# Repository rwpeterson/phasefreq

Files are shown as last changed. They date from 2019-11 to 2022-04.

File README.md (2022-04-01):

# phasefreq
 Phase-frequency detector PCB built around the AD9901

## Design goals

* Simple, connectorized element to replace an analog mixer in rf test setups
* Requires only dc power to operate (no programming)
* 10 MHz, ideally 100 MHz bandwidth (10 MHz is reasonable without impedance control in fabrication)
* Accommodate analog input (Analog ADCMP564 comparator, with settable threshold and hysteresis)
* Perform PFD calculation (Analog AD9901 phase-frequency discriminator, ECL logic family)
* Low-pass filter to convert PFD output's pulse train duty cycle to a dc voltage
* Tunable output offset, jumper-switchable sign of gain
* This is basically a subset of the reference design in Fig. 12 of the [AD9901 datasheet](https://www.analog.com/media/en/technical-documentation/data-sheets/AD9901.pdf), which describes a complete PLL circuit with discrete comparator, PFD, VCO, divider, etc. Here we wish to implement only the comparator, phase-frequency detector, and loop filter

## What is a PFD?

A phase-frequency detector (or phase-frequency discriminator) is similar to an analog mixer, in that if the LO and RF frequencies are the same, its output is proportional to the relative phase between them. However, if the LO and RF frequencies differ, a PFD will output a constant voltage whose sign indicates which of the two frequencies is larger. In this case, an analog mixer would produce IF beatnotes at the sum and difference frequencies. This second characteristic of a PFD is useful to more quickly bring a feedback system such as a PLL into lock.

## Other options?

Of course, an analog mixer may be perfectly suitable for your application. More sophisticated PLL ICs contain builtin PFDs as part of the feedback loop. Some evaluation boards expose enough functionality to use them solely as a PFD, but they are prohibitively expensive for many applications where a simple PFD would be beneficial, and often need to be programmed or initialized at the point of use.

## Characterization

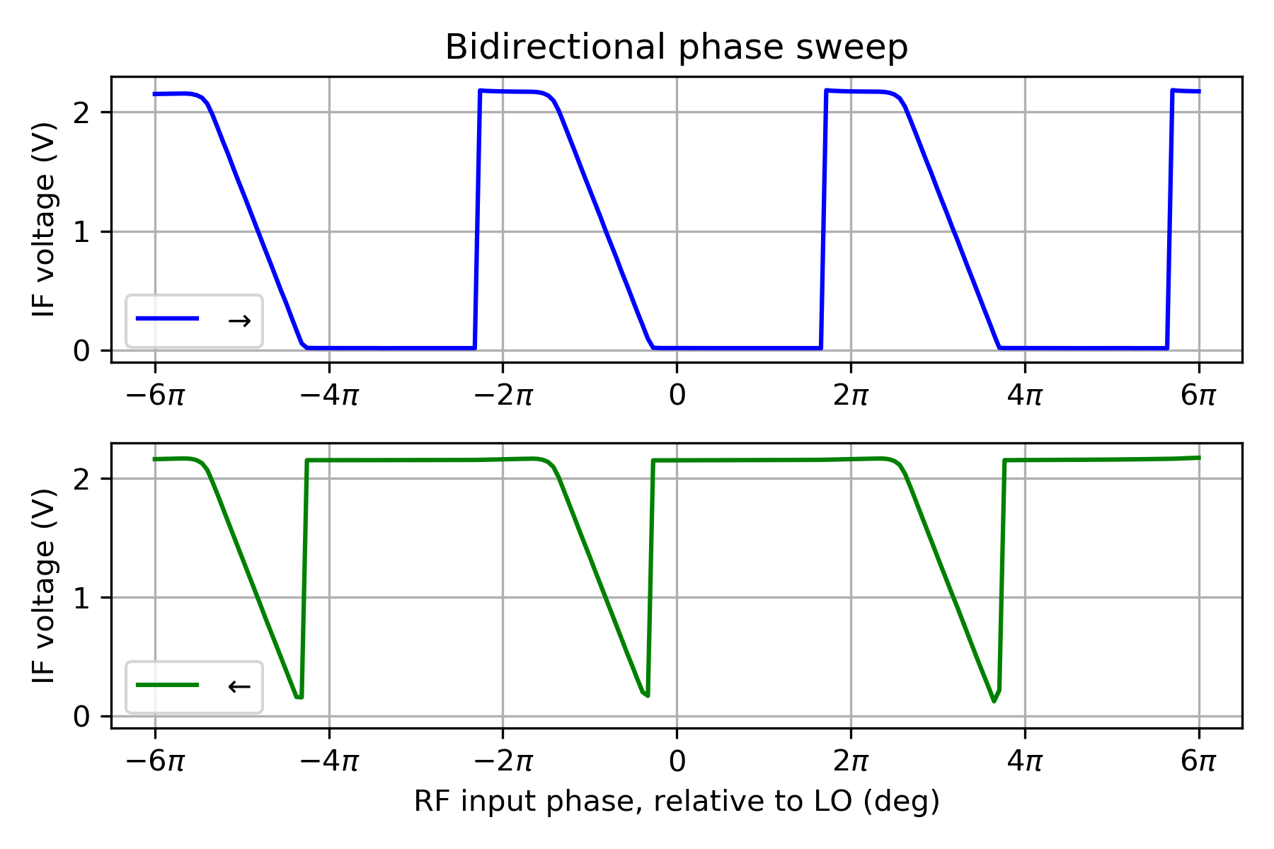
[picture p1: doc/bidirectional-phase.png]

### Figure 1: Bidirectional phase sweep (RF and LO at 10 MHz)
Scanning the relative phase of the inputs demonstrates the linear phase detection and capture range. The location of the linear phase detection is modulo 2 pi as expected. However, when the phase is scanned away from a given phase detection range, the IF output will rail for one additional phase cycle before phase-slipping to the *second* capture range 4 pi away (as shown). For frequencies > 50 MHz, the ends of the phase detection range will be distorted (see AD9901 datasheet, Fig. 7).

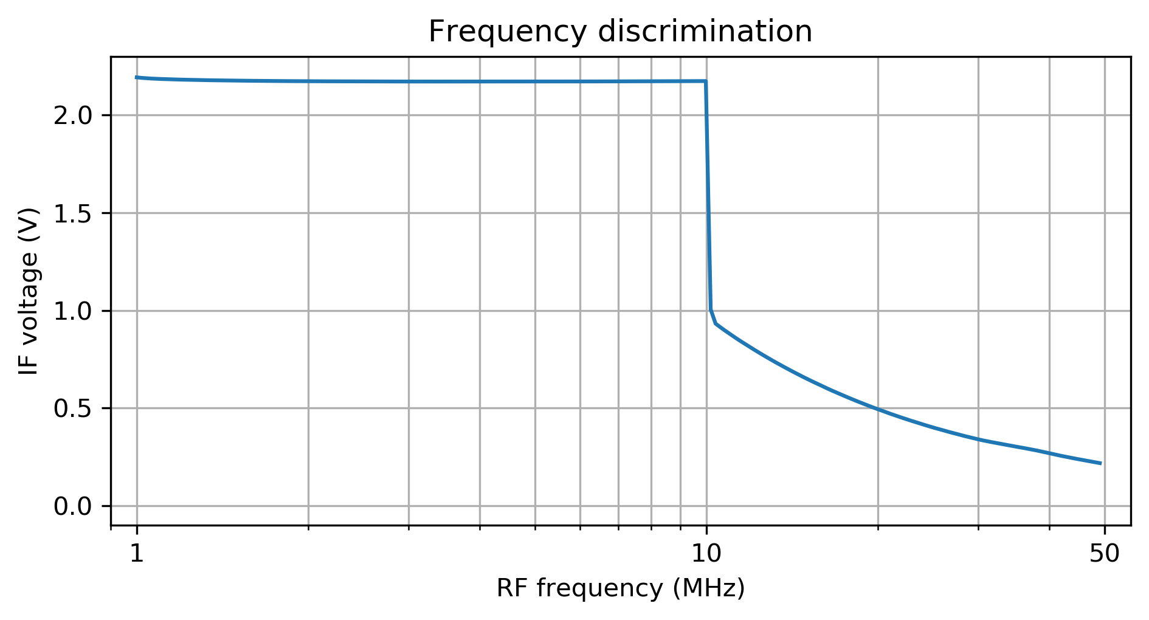
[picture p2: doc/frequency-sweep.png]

### Figure 2: Frequency discrimination characteristic, LO = 10 MHz
When the RF and LO frequencies differ substantially, the PFD outputs a constant voltage indicating which is higher.

## Prototype

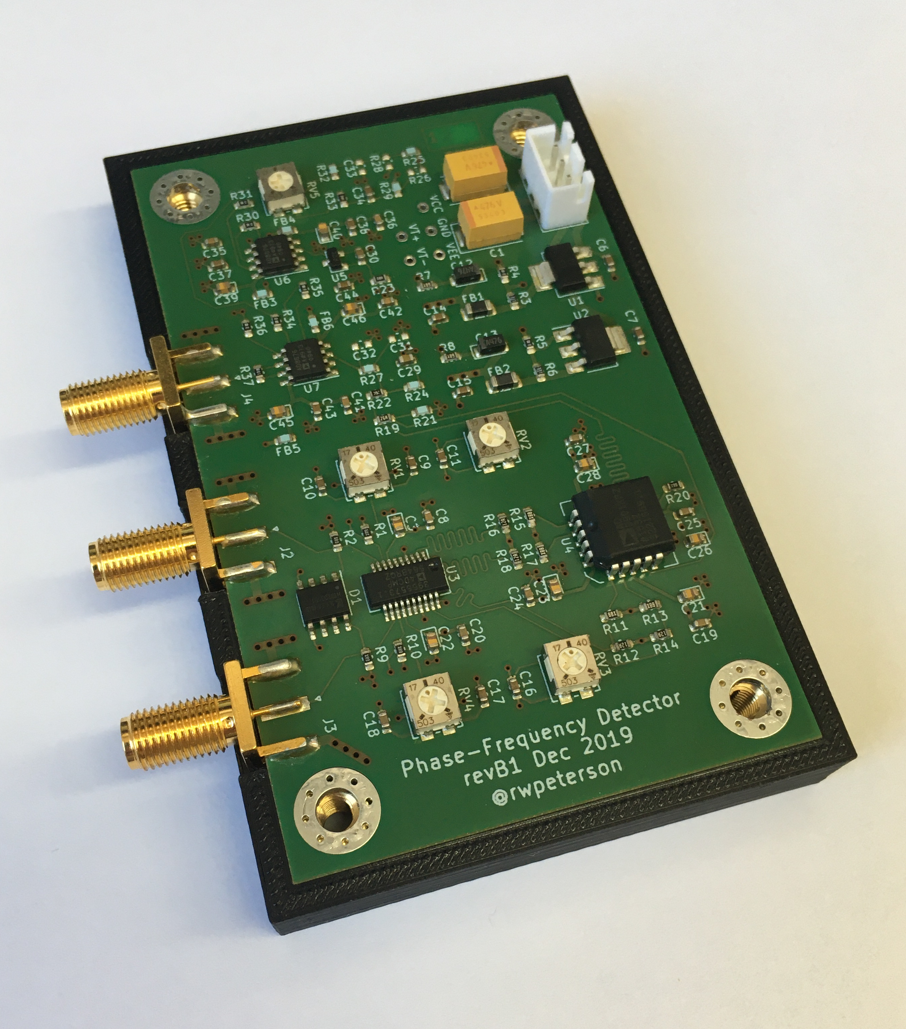
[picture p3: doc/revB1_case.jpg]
Prototype

### Figure 3: revB1 prototype in 3D-printed case (lid removed)
This is the device used for the above characterization plots.

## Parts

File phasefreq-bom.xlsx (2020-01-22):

Source: | phasefreq.sch
Date: | 2019-11-12 11:08
Tool: | Eeschema (5.1.2)-1
Generator: | C:\Program Files\KiCad\bin\scripting\plugins/bom_csv_grouped_by_value_with_fp.py
Component Count: | 100
Ref | Qnty | Value | Cmp name | Footprint | Description | Vendor | Link
C1, C4, | 2 | 47u | CP_Small | Capacitor_Tantalum_SMD:CP_EIA-7343-43_Kemet-X | Polarized capacitor, small symbol |  | https://www.digikey.at/product-detail/en/avx-corporation/TAJE476K035RNJ/478-3074-1-ND/809587
C8, C20, C27, C25, C19, C24, | 6 | 10n | C_Small | Capacitor_SMD:C_0603_1608Metric | Unpolarized capacitor, small symbol |  | https://www.digikey.at/product-detail/en/murata-electronics/GCJ188R71H103KA01D/490-5762-1-ND/2782239
C13, C12, | 2 | 47u | CP_Small | Capacitor_Tantalum_SMD:CP_EIA-3216-18_Kemet-A | Polarized capacitor, small symbol |  | https://www.digikey.at/product-detail/en/avx-corporation/F931A476KAA/478-8223-1-ND/4005652
C17, C18, C43, C44, C14, C15, C7, C11, C16, C6, C37, C38, C30, C10, C9, C34, | 16 | 100n | C_Small | Capacitor_SMD:C_0603_1608Metric | Unpolarized capacitor, small symbol |  | https://www.digikey.at/product-detail/en/murata-electronics/GCJ188R71H104KA12D/490-5798-1-ND/2783823
C22, C26, C21, C23, C3, C28, | 6 | 1u | CP_Small | Capacitor_Tantalum_SMD:CP_EIA-1608-10_AVX-L | Polarized capacitor, small symbol |  | https://www.digikey.at/product-detail/en/avx-corporation/TACL105K010RTA/478-7521-1-ND/3660394
C29, | 1 | 1u | C_Small | Capacitor_SMD:C_0603_1608Metric | Unpolarized capacitor, small symbol |  | https://www.digikey.at/product-detail/en/taiyo-yuden/UMK107AB7105KA-T/587-3247-1-ND/3660107
C32, C31, C33, | 3 | DNP | C_Small | Capacitor_SMD:C_0603_1608Metric | Unpolarized capacitor, small symbol |  | -
C41, C42, C35, C36, | 4 | 1n | C_Small | Capacitor_SMD:C_0603_1608Metric | Unpolarized capacitor, small symbol |  | https://www.digikey.at/product-detail/en/murata-electronics/GCJ188R71H102KA01D/490-5768-1-ND/2782248
C45, C46, C39, C40, | 4 | 4u7 | CP_Small | Capacitor_Tantalum_SMD:CP_EIA-1608-10_AVX-L | Polarized capacitor, small symbol |  | https://www.digikey.at/product-detail/en/avx-corporation/TPCL475K010R5000/478-4961-1-ND/1879558
D1, | 1 | SLVU2.8-8 | SLVU2.8-8 | Package_SO:SOIC-8_3.9x4.9mm_P1.27mm | SLVU2.8-8 Series 2.8V 30A TVS Array |  | https://www.digikey.at/product-detail/en/littelfuse-inc/SLVU2.8-8BTG/F6745CT-ND/5428749
FB2, FB1, | 2 | BLM31PG601SN1L | Ferrite_Bead_Small | Inductor_SMD:L_1206_3216Metric | Ferrite bead, small symbol |  | https://www.digikey.at/product-detail/en/murata-electronics/BLM31PG601SN1L/490-1057-1-ND/584503
J1, | 1 | Power Input | Conn_01x03_Female | Connector_JST:JST_XH_B3B-XH-A_1x03_P2.50mm_Vertical | Generic connector, single row, 01x03, script generated (kicad-library-utils/schlib/autogen/connector/) |  | -
J2, | 1 | RF Input | Conn_Coaxial | Connector_Coaxial:SMA_Amphenol_132289_EdgeMount | coaxial connector (BNC, SMA, SMB, SMC, Cinch/RCA, ...) |  | https://www.digikey.at/product-detail/en/amphenol-rf/132289/ACX1426-ND/1989875
J3, | 1 | LO Input | Conn_Coaxial | Connector_Coaxial:SMA_Amphenol_132289_EdgeMount | coaxial connector (BNC, SMA, SMB, SMC, Cinch/RCA, ...) |  | ^
J4, | 1 | VCO Tune | Conn_Coaxial | Connector_Coaxial:SMA_Amphenol_132289_EdgeMount | coaxial connector (BNC, SMA, SMB, SMC, Cinch/RCA, ...) |  | ^
R2, R10, R9, R1, | 4 | 49R9 | R_Small | Resistor_SMD:R_0603_1608Metric | Resistor, small symbol |  | https://www.digikey.at/product-detail/en/stackpole-electronics-inc/RNCP0603FTD49R9/RNCP0603FTD49R9CT-ND/2240419
R6, R3, | 2 | 330 | R_Small | Resistor_SMD:R_0603_1608Metric | Resistor, small symbol |  | https://www.digikey.at/product-detail/en/yageo/RT0603FRE07330RL/YAG5957CT-ND/9370987
R8, R7, | 2 | 5R0 | R_Small | Resistor_SMD:R_0603_1608Metric | Resistor, small symbol |  | https://www.digikey.at/product-detail/en/te-connectivity-passive-product/CPF0603F4R99C1/A102290CT-ND/2728264
R11, R13, R15, R17, | 4 | 80R6 | R_Small | Resistor_SMD:R_0603_1608Metric | Resistor, small symbol |  | https://www.digikey.at/product-detail/en/te-connectivity-passive-product/RP73PF1J80R6BTDF/A110003CT-ND/4034358
R12, R14, R16, R18, | 4 | 130 | R_Small | Resistor_SMD:R_0603_1608Metric | Resistor, small symbol |  | https://www.digikey.at/product-detail/en/te-connectivity-passive-product/RP73PF1J130RBTDF/A110023CT-ND/4034378
R19, | 1 | 182 | R_Small | Resistor_SMD:R_0603_1608Metric | Resistor, small symbol |  | https://www.digikey.at/product-detail/en/te-connectivity-passive-product/RP73PF1J182RBTDF/A110037CT-ND/4034392
R20, | 1 | 47R5 | R_Small | Resistor_SMD:R_0603_1608Metric | Resistor, small symbol |  | https://www.digikey.at/product-detail/en/stackpole-electronics-inc/RNCP0603FTD47R5/RNCP0603FTD47R5CT-ND/2240418
R22, | 1 | 18K2 | R_Small | Resistor_SMD:R_0603_1608Metric | Resistor, small symbol |  | https://www.digikey.at/product-detail/en/stackpole-electronics-inc/RNCP0603FTD18K2/RNCP0603FTD18K2CT-ND/2240486
R23, | 1 | 499R | R_Small | Resistor_SMD:R_0603_1608Metric | Resistor, small symbol |  | https://www.digikey.at/product-detail/en/stackpole-electronics-inc/RNCP0603FTD499R/RNCP0603FTD499RCT-ND/2240437
R24, | 1 | 110 | R_Small | Resistor_SMD:R_0603_1608Metric | Resistor, small symbol |  | https://www.digikey.at/product-detail/en/vishay-beyschlag/MCT06030C1100FP500/749-MCT06030C1100FP500CT-ND/10453856
R27, R21, R32, R29, R25, | 5 | 0R0 | R_Small | Resistor_SMD:R_0603_1608Metric | Resistor, small symbol |  | https://www.digikey.at/product-detail/en/vishay-beyschlag/MCT06030Z0000ZP500/MCT0603-0.0-ZZCT-ND/2607921
R28, R26, | 2 | DNP | R_Small | Resistor_SMD:R_0603_1608Metric | Resistor, small symbol |  | -
R33, | 1 | 28K | R_Small | Resistor_SMD:R_0603_1608Metric | Resistor, small symbol |  | https://www.digikey.at/product-detail/en/stackpole-electronics-inc/RNCP0603FTD28K0/RNCP0603FTD28K0CT-ND/2240493
R35, R34, R5, R4, R30, R31, R36, | 7 | 1K | R_Small | Resistor_SMD:R_0603_1608Metric | Resistor, small symbol |  | https://www.digikey.at/product-detail/en/stackpole-electronics-inc/RNCP0603FTD1K00/RNCP0603FTD1K00CT-ND/2240445
R37, | 1 | 1K50 | R_Small | Resistor_SMD:R_0603_1608Metric | Resistor, small symbol |  | https://www.digikey.at/product-detail/en/stackpole-electronics-inc/RNCP0603FTD1K50/RNCP0603FTD1K50CT-ND/2240449
RV2, RV3, RV1, RV4, RV5, | 5 | 50K | R_POT | Potentiometer_SMD:Potentiometer_Vishay_TS53YJ_Vertical | Potentiometer |  | https://www.digikey.at/product-detail/en/vishay-sfernice/TS53YJ503MR10/TS53YJ-50KCT-ND/1587989
U1, | 1 | LM317_3PinPackage | LM317_3PinPackage | Package_TO_SOT_SMD:SOT-223-3_TabPin2 | 1A 35V Adjustable Linear Regulator, SOT-89/SOT-223/TO-220/TO-252/TO-263 |  | https://www.digikey.at/product-detail/en/texas-instruments/LM317DCY/296-23224-5-ND/1510131
U2, | 1 | LM337_SOT223 | LM337_SOT223 | Package_TO_SOT_SMD:SOT-223-3_TabPin2 | Negative 1A 35V Adjustable Linear Regulator, SOT-223 |  | https://www.digikey.at/product-detail/en/texas-instruments/LM337IMP-NOPB/LM337IMP-NOPBCT-ND/270746
U3, | 1 | ADCMP564 | ADCMP564 | Package_SO:QSOP-20_3.9x8.7mm_P0.635mm |  |  | https://www.digikey.at/product-detail/en/analog-devices-inc/ADCMP564BRQZ/ADCMP564BRQZ-ND/997466
U4, | 1 | AD9901 | AD9901 | Package_LCC:PLCC-20 |  |  | https://www.digikey.at/product-detail/en/analog-devices-inc/AD9901KPZ/AD9901KPZ-ND/820034
U5, | 1 | LM4040DIZ-2.5 | LM4040DBZ-3 | Package_TO_SOT_SMD:SOT-23 | 3.000V Precision Micropower Shunt Voltage Reference, SOT-23 |  | https://www.digikey.at/product-detail/en/diodes-incorporated/LM4040C25FTA/LM4040C25FCT-ND/1557754
U6, U7, | 2 | AD8676 | AD8676 | Package_SO:SOIC-8_3.9x4.9mm_P1.27mm |  |  | https://www.digikey.at/product-detail/en/analog-devices-inc/AD8676ARZ-REEL7/AD8676ARZ-REEL7CT-ND/3828889

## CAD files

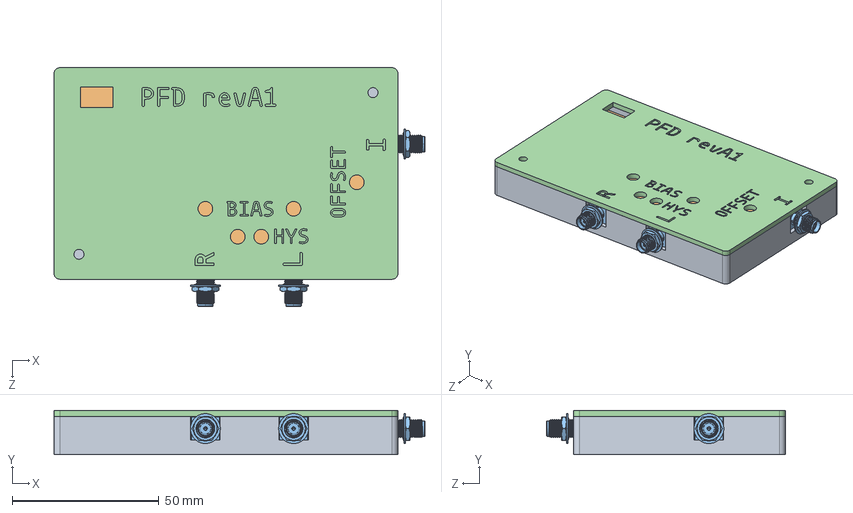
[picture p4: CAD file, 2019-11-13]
Enclosure/PFD Enclosure.SLDASM
126.2 x 15.0 x 81.2 mm
PFD Enclosure Base
PFD Board Primitive
PFD Enclosure Lid

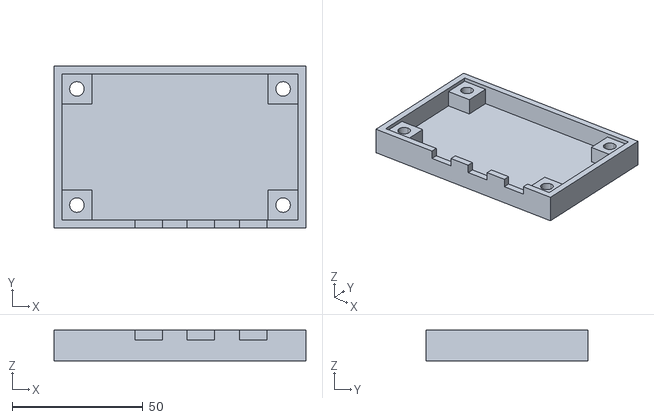
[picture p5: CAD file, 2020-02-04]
enclosure-base.stl
96.5 x 62.0 x 11.8

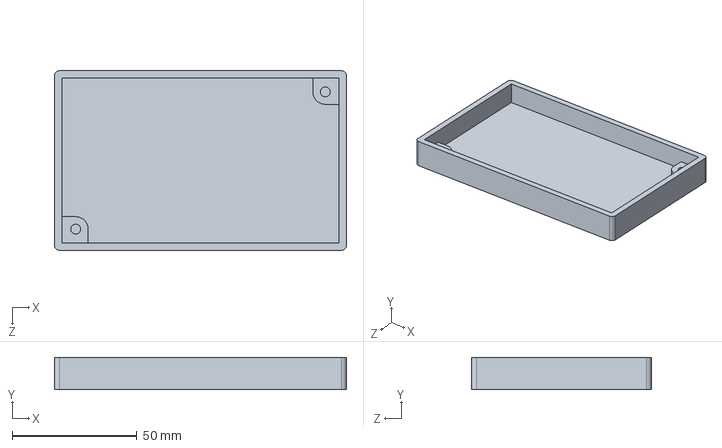
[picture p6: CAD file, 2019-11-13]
Enclosure/PFD Enclosure Base.SLDPRT
117.0 x 13.0 x 72.0 mm

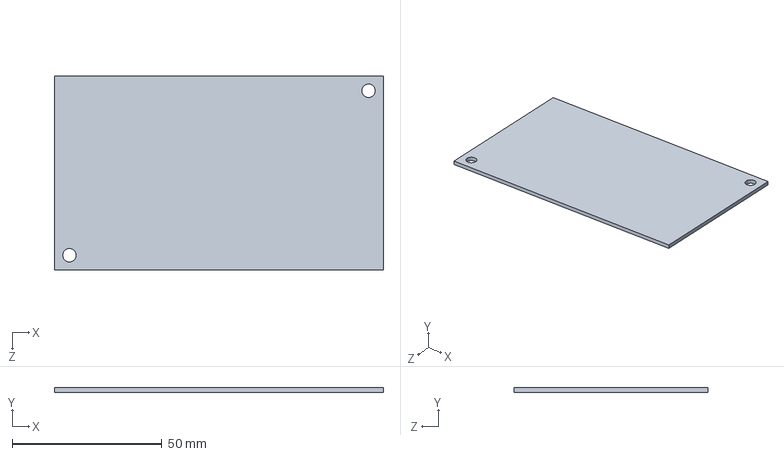
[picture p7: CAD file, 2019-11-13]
Enclosure/PFD Board Primitive.SLDPRT
110.0 x 1.60 x 65.0 mm

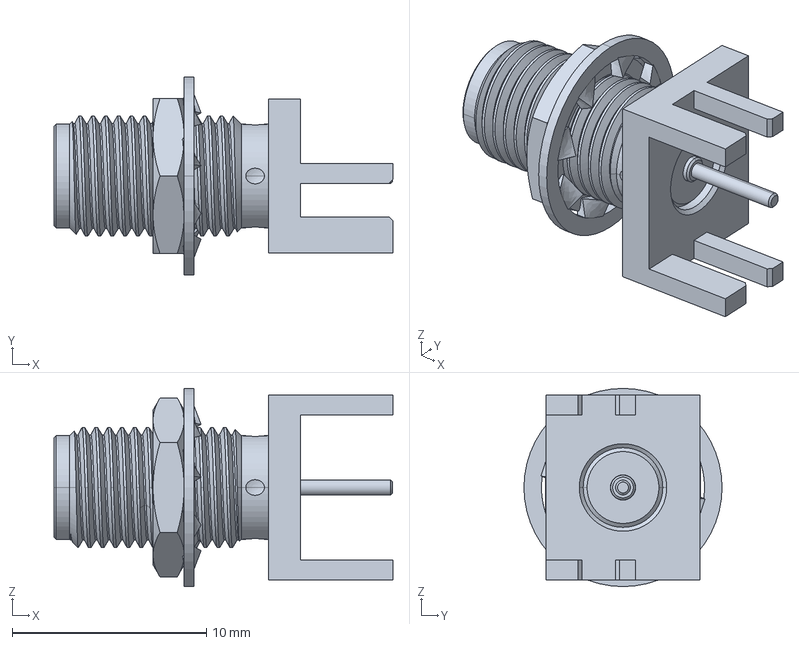
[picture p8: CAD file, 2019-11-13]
Enclosure/132289.stp
17.5 x 10.2 x 10.2 mm

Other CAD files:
Enclosure/PFD Enclosure Lid.sldprt
phasefreq.wrl_0.sldprt
Enclosure/PFD Board.sldprt
Enclosure/132289.SLDPRT
Enclosure/PFD Enclosure Base.STL
Enclosure/PFD Enclosure Lid.STL

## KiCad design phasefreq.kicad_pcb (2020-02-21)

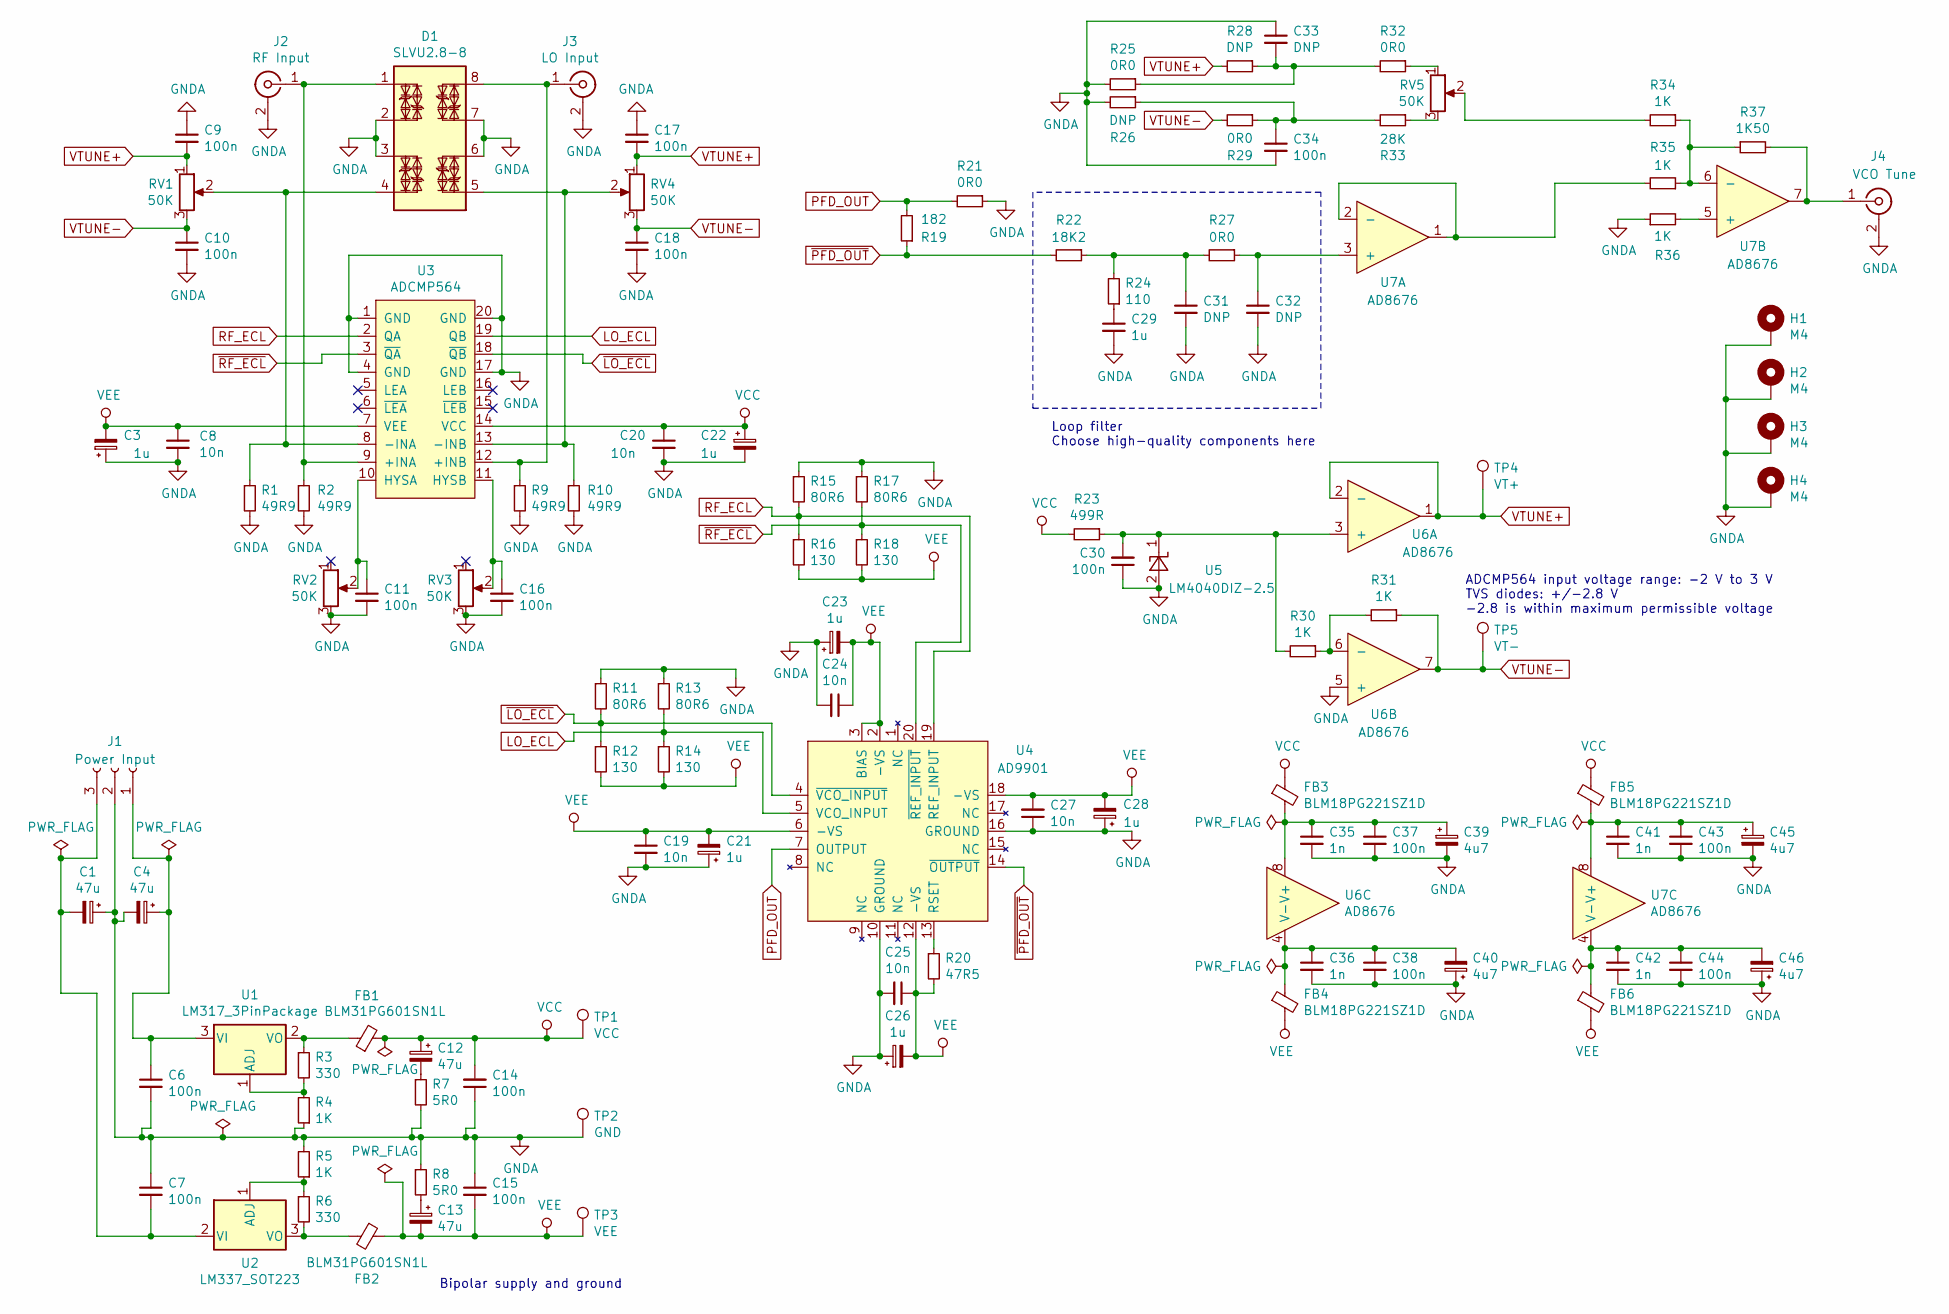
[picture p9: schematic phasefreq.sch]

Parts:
C1, C4: 47u; CP_EIA-7343-43_Kemet-X
C3, C21, C22, C23, C26, C28: 1u; CP_EIA-1608-10_AVX-L
C6, C7, C9, C10, C11, C14, C15, C16, C17, C18, C30, C34, C37, C38, C43, C44: 100n; C_0603_1608Metric
C8, C19, C20, C24, C25, C27: 10n; C_0603_1608Metric
C12, C13: 47u; CP_EIA-3216-18_Kemet-A
C29: 1u; C_0603_1608Metric
C31, C32, C33: DNP; C_0603_1608Metric
C35, C36, C41, C42: 1n; C_0603_1608Metric
C39, C40, C45, C46: 4u7; CP_EIA-1608-10_AVX-L
D1: SLVU2.8-8; SOIC-8_3.9x4.9mm_P1.27mm
FB1, FB2: BLM31PG601SN1L; L_1206_3216Metric
FB3, FB4, FB5, FB6: BLM18PG221SZ1D; L_0603_1608Metric
H1, H2, H3, H4: M4; MountingHole_4.3mm_M4_Pad_Via
J1: Power Input; JST_XH_B3B-XH-A_1x03_P2.50mm_Vertical
J2: RF Input; SMA_Amphenol_132289_EdgeMount
J3: LO Input; SMA_Amphenol_132289_EdgeMount
J4: VCO Tune; SMA_Amphenol_132289_EdgeMount
R1, R2, R9, R10: 49R9; R_0603_1608Metric
R3, R6: 330; R_0603_1608Metric
R4, R5, R30, R31, R34, R35, R36: 1K; R_0603_1608Metric
R7, R8: 5R0; R_0603_1608Metric
R11, R13, R15, R17: 80R6; R_0603_1608Metric
R12, R14, R16, R18: 130; R_0603_1608Metric
R19: 182; R_0603_1608Metric
R20: 47R5; R_0603_1608Metric
R21, R25, R27, R29, R32: 0R0; R_0603_1608Metric
R22: 18K2; R_0603_1608Metric
R23: 499R; R_0603_1608Metric
R24: 110; R_0603_1608Metric
R26, R28: DNP; R_0603_1608Metric
R33: 28K; R_0603_1608Metric
R37: 1K50; R_0603_1608Metric
RV1, RV2, RV3, RV4, RV5: 50K; Potentiometer_Vishay_TS53YJ_Vertical
TP1: VCC; TestPoint_THTPad_D1.5mm_Drill0.7mm
TP2: GND; TestPoint_THTPad_D1.5mm_Drill0.7mm
TP3: VEE; TestPoint_THTPad_D1.5mm_Drill0.7mm
TP4: VT+; TestPoint_THTPad_D1.5mm_Drill0.7mm
TP5: VT-; TestPoint_THTPad_D1.5mm_Drill0.7mm
U1: LM317_3PinPackage; SOT-223-3_TabPin2
U2: LM337_SOT223; SOT-223-3_TabPin2
U3: ADCMP564; QSOP-20_3.9x8.7mm_P0.635mm
U4: AD9901; PLCC-20
U5: LM4040DIZ-2.5; SOT-23
U6, U7: AD8676; SOIC-8_3.9x4.9mm_P1.27mm

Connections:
GNDA: C1.1, C3.1, C4.2, C6.2, C7.1, C8.2, C9.1, C10.2, C11.2, C14.1, C15.1, C16.2, C17.1, C18.2, C19.2, C20.2, C21.1, C22.2, C23.1, C24.2, C25.2, C26.1, C27.1, C28.1, C29.2, C30.1, C31.2, C32.2, C33.1, C34.2, C35.2, C36.2, C37.2, C38.2, C39.2, C40.1, C41.2, C42.2, C43.2, C44.2, C45.2, C46.1, D1.2 (TVS2), D1.3 (TVS1), D1.6 (TVS2), D1.7 (TVS1), H1.1, H2.1, H3.1, H4.1, J1.2, J2.2 (Ext), J3.2 (Ext), J4.2 (Ext), R1.2, R2.2, R4.1, R5.2, R7.2, R8.1, R9.2, R10.2, R11.1, R13.1, R15.1, R17.1, R21.1, R25.2, R26.2, R36.1, RV2.3, RV3.3, TP2.1, U3.1 (GND), U3.4 (GND), U3.17 (GND), U3.20 (GND), U4.10 (GROUND), U4.16 (GROUND), U5.2 (A), U6.5 (+); also elsewhere on the board
LO_ECL: R13.2, R14.1, U3.19 (QB), U4.5 (VCO_INPUT)
unnamed: C1.2, C7.2, J1.3, U2.2 (VI)
unnamed: C4.1, C6.1, J1.1, U1.3 (VI)
unnamed: C11.1, RV2.2, U3.10 (HYSA)
unnamed: C12.2, R7.1
unnamed: C13.1, R8.2
unnamed: C16.1, RV3.2, U3.11 (HYSB)
unnamed: C29.1, R24.1
unnamed: C30.2, R23.1, R30.2, U5.1 (K), U6.3 (+)
unnamed: C31.1, R22.1, R24.2, R27.2
unnamed: C32.1, R27.1, U7.3 (+)
unnamed: C33.2, R25.1, R28.1, R32.2
unnamed: C34.1, R26.1, R29.1, R33.2
unnamed: C35.1, C37.1, C39.1, FB3.2, U6.8 (V+)
unnamed: C36.1, C38.1, C40.2, FB4.1, U6.4 (V-)
unnamed: C41.1, C43.1, C45.1, FB5.2, U7.8 (V+)
unnamed: C42.1, C44.1, C46.2, FB6.1, U7.4 (V-)
unnamed: D1.1 (TVS1), J2.1 (In), R2.1, U3.9 (+INA)
unnamed: D1.4 (TVS2), R1.1, RV1.2, U3.8 (-INA)
unnamed: D1.5 (TVS1), R10.1, RV4.2, U3.13 (-INB)
unnamed: D1.8 (TVS2), J3.1 (In), R9.1, U3.12 (+INB)
unnamed: FB1.1, R3.1, U1.2 (VO)
unnamed: FB2.2, R6.2, U2.3 (VO)
unnamed: J4.1 (In), R37.2, U7.7
unnamed: R3.2, R4.2, U1.1 (ADJ)
unnamed: R5.1, R6.1, U2.1 (ADJ)
unnamed: R20.1, U4.13 (RSET)
unnamed: R30.1, R31.2, U6.6 (-)
unnamed: R32.1, RV5.1
unnamed: R33.1, RV5.3
unnamed: R34.1, R35.1, R37.1, U7.6 (-)
unnamed: R34.2, RV5.2
unnamed: R35.2, U7.1, U7.2 (-)
unnamed: R36.2, U7.5 (+)
PFD_OUT: R19.2, R21.2, U4.7 (OUTPUT)
RF_ECL: R15.2, R16.1, U3.2 (QA), U4.19 (REF_INPUT)
VCC: C12.1, C14.2, C20.1, C22.1, FB1.2, FB3.1, FB5.1, R23.2, TP1.1, U3.14 (VCC); also elsewhere on the board
VEE: C3.2, C8.1, C13.2, C15.2, C19.1, C21.2, C23.2, C24.1, C25.1, C26.2, C27.2, C28.2, FB2.1, FB4.2, FB6.2, R12.2, R14.2, R16.2, R18.2, R20.2, TP3.1, U3.7 (VEE), U4.2 (-VS), U4.3 (BIAS), U4.6 (-VS), U4.12 (-VS), U4.18 (-VS); also elsewhere on the board
VTUNE+: C9.2, C17.2, R28.2, RV1.1, RV4.1, TP4.1, U6.1, U6.2 (-); also elsewhere on the board
VTUNE-: C10.1, C18.1, R29.2, R31.1, RV1.3, RV4.3, TP5.1, U6.7; also elsewhere on the board
~LO_ECL~: R11.2, R12.1, U3.18 (~QB~), U4.4 (~VCO_INPUT~)
~PFD_OUT~: R19.1, R22.2, U4.14 (~OUTPUT~)
~RF_ECL~: R17.2, R18.1, U3.3 (~QA~), U4.20 (~REF_INPUT)

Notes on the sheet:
Loop filter Choose high-quality components here
Bipolar supply and ground
ADCMP564 input voltage range: -2 V to 3 V TVS diodes: +/-2.8 V -2.8 is within maximum permissible voltage

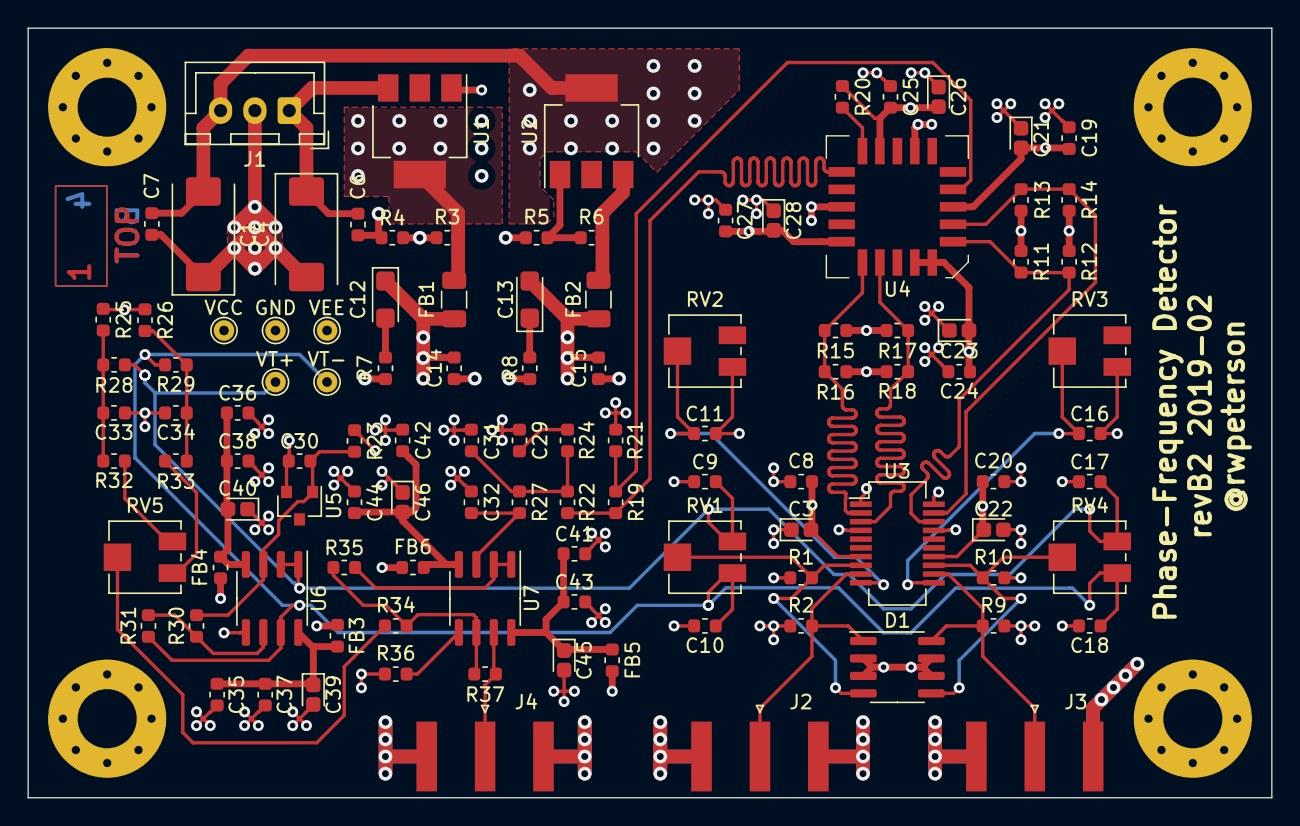
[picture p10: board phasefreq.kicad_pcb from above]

Board: 4 copper layers, 90.5 x 56.0 mm, 113 parts (0 on the bottom side), 44 nets.

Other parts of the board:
GND: GND; TestPoint_THTPad_D1.5mm_Drill0.7mm
VCC: VCC; TestPoint_THTPad_D1.5mm_Drill0.7mm
VEE: VEE; TestPoint_THTPad_D1.5mm_Drill0.7mm
VT+: VT+; TestPoint_THTPad_D1.5mm_Drill0.7mm
VT-: VT-; TestPoint_THTPad_D1.5mm_Drill0.7mm

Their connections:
GNDA: GND.1; also elsewhere on the board
VCC: VCC.1; also elsewhere on the board
VEE: VEE.1; also elsewhere on the board
VTUNE+: VT+.1; also elsewhere on the board
VTUNE-: VT-.1; also elsewhere on the board

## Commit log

2019-11-13 init revA1
    [132289.SLDPRT, 132289.stp, PFD Board Primitive.SLDPRT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]
2019-11-13 Fixed bugs found in revA1 fab
    Fixed U5 wiring flip, R23 value so U7 has enough current, added jumpers to flip input to differential amplifier U9B, made bias to U9B bipolar
    [phasefreq.sch]
2019-11-13 Cleaned up power, regularized pot values
    Switched all power references to single bipolar supply, consolidated to a single ground, and set all pot values to be the same (constrained by R_hys on comparators)
    [phasefreq.sch]
2019-11-14 switch power from labels to proper power port
    [phasefreq.sch]
2019-11-14 Added TVS diode array to comparator input
    [phasefreq.sch]
2019-11-15 notations for future work
    [phasefreq.sch]
2019-11-18 added ADCMP565 component, sch annotations for future changes
    [phasefreq.sch]
2019-11-19 cleaned up bypass caps, comp for new adcmp
    [phasefreq.sch]
2019-12-04 cleaned up loop filter (up to 3rd order possible) and subs. gain stages
    [phasefreq.sch]
2019-12-05 Switched to Thevenin termination of inputs to AD9901
    [phasefreq.sch]
2019-12-05 changed Vbias to be +/- 2.5 V to accomodate TVS diodes
    [phasefreq.sch]
2019-12-05 Set offset on output to match possible PLL filter outputs, checked LM4040-2.5 resistor value
    [phasefreq.sch]
2019-12-06 Finished schematic, relabeled components, ready for layout
    [phasefreq.sch]
2019-12-06 fixed some cap footprints, started layout
    [phasefreq.kicad_pcb, phasefreq.sch]
2019-12-09 basic layout of board, removed superfluous caps
    [phasefreq.kicad_pcb, phasefreq.sch]
2019-12-09 routed major components, added draft board outline
    [phasefreq.kicad_pcb]
2019-12-10 routed almost everything, shrunk board dimensions a bit
    [phasefreq.kicad_pcb]
2019-12-10 cleaned up the keepout for layer orientation marks
    [phasefreq.kicad_pcb]
2019-12-10 missing trace fixed, drc now passes
    [phasefreq.kicad_pcb]
2019-12-11 added mounting holes and test points to sch, added ferrite beads to op amp supplies
    [phasefreq.kicad_pcb, phasefreq.sch]
2019-12-11 fixed cosmetic trace and zone issues
    [phasefreq.kicad_pcb]
2020-01-15 added bom with distributor links
    [phasefreq-bom.xlsx]
2020-01-22 changed bom, one wrong part, some out of stock at time of order
    [phasefreq-bom.xlsx]
2020-02-04 new enclosure for revB1
    [enclosure-base.stl]
2020-02-21 add thermal pads for regulators, increment to revB2
    [phasefreq.kicad_pcb]
2022-04-01 Add photograph of prototype PCB
2022-04-01 fixup! Add photograph of prototype PCB
